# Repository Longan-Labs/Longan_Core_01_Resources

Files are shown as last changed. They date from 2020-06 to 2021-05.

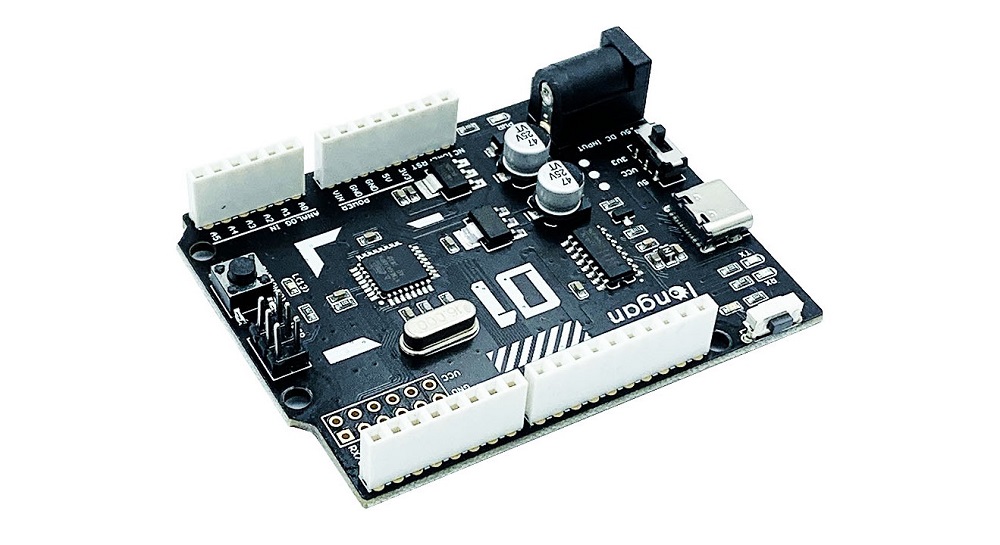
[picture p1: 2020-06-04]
images/1040008-2.jpg

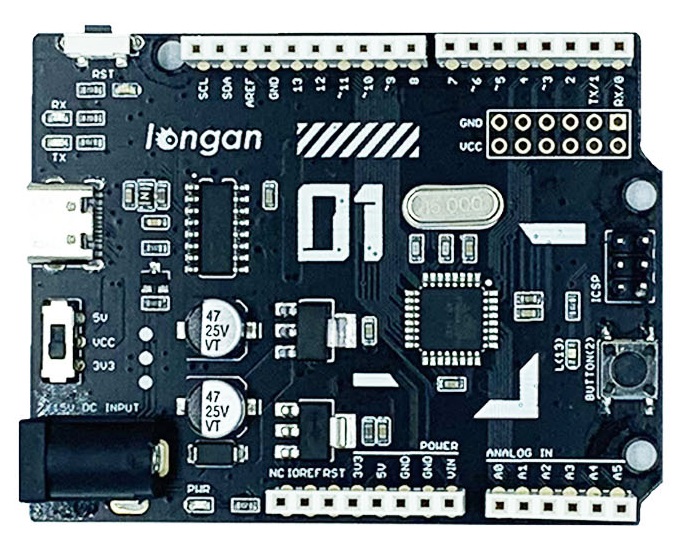
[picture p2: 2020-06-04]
images/1040008-1.jpg

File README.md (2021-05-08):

(https://www.longan-labs.cc/platform/arduino.html)

Resources of [Longan Core 01](https://www.longan-labs.cc/1040009.html)

Include:

1. Eagle File
2. Images
3. Drivers for CH340

Click on [Longan-Labs.cc](https://www.longan-labs.cc/) to get the product you need.

Contact [support@longan-labs.cc](support@longan-labs.cc) if you need help.

Analytics (https://github.com/igrigorik/ga-beacon)

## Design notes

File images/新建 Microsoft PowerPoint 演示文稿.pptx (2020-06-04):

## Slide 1

9


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
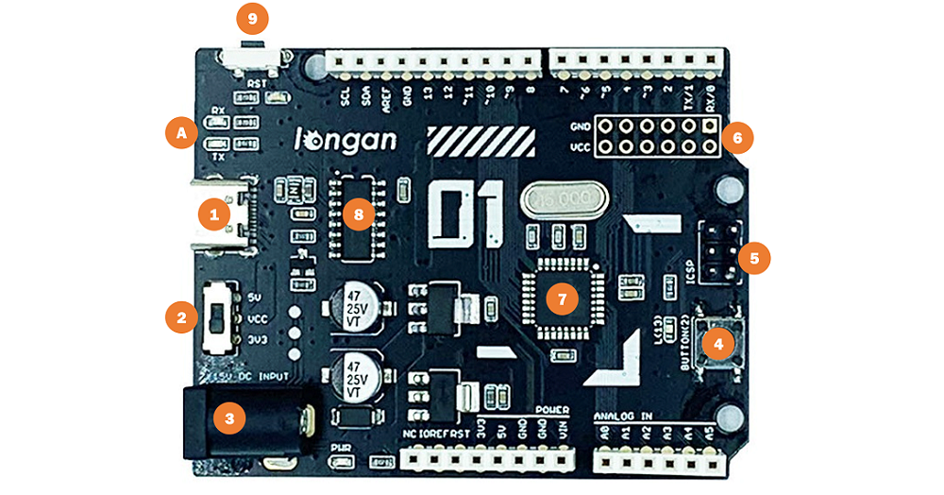
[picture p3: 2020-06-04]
images/hw.png

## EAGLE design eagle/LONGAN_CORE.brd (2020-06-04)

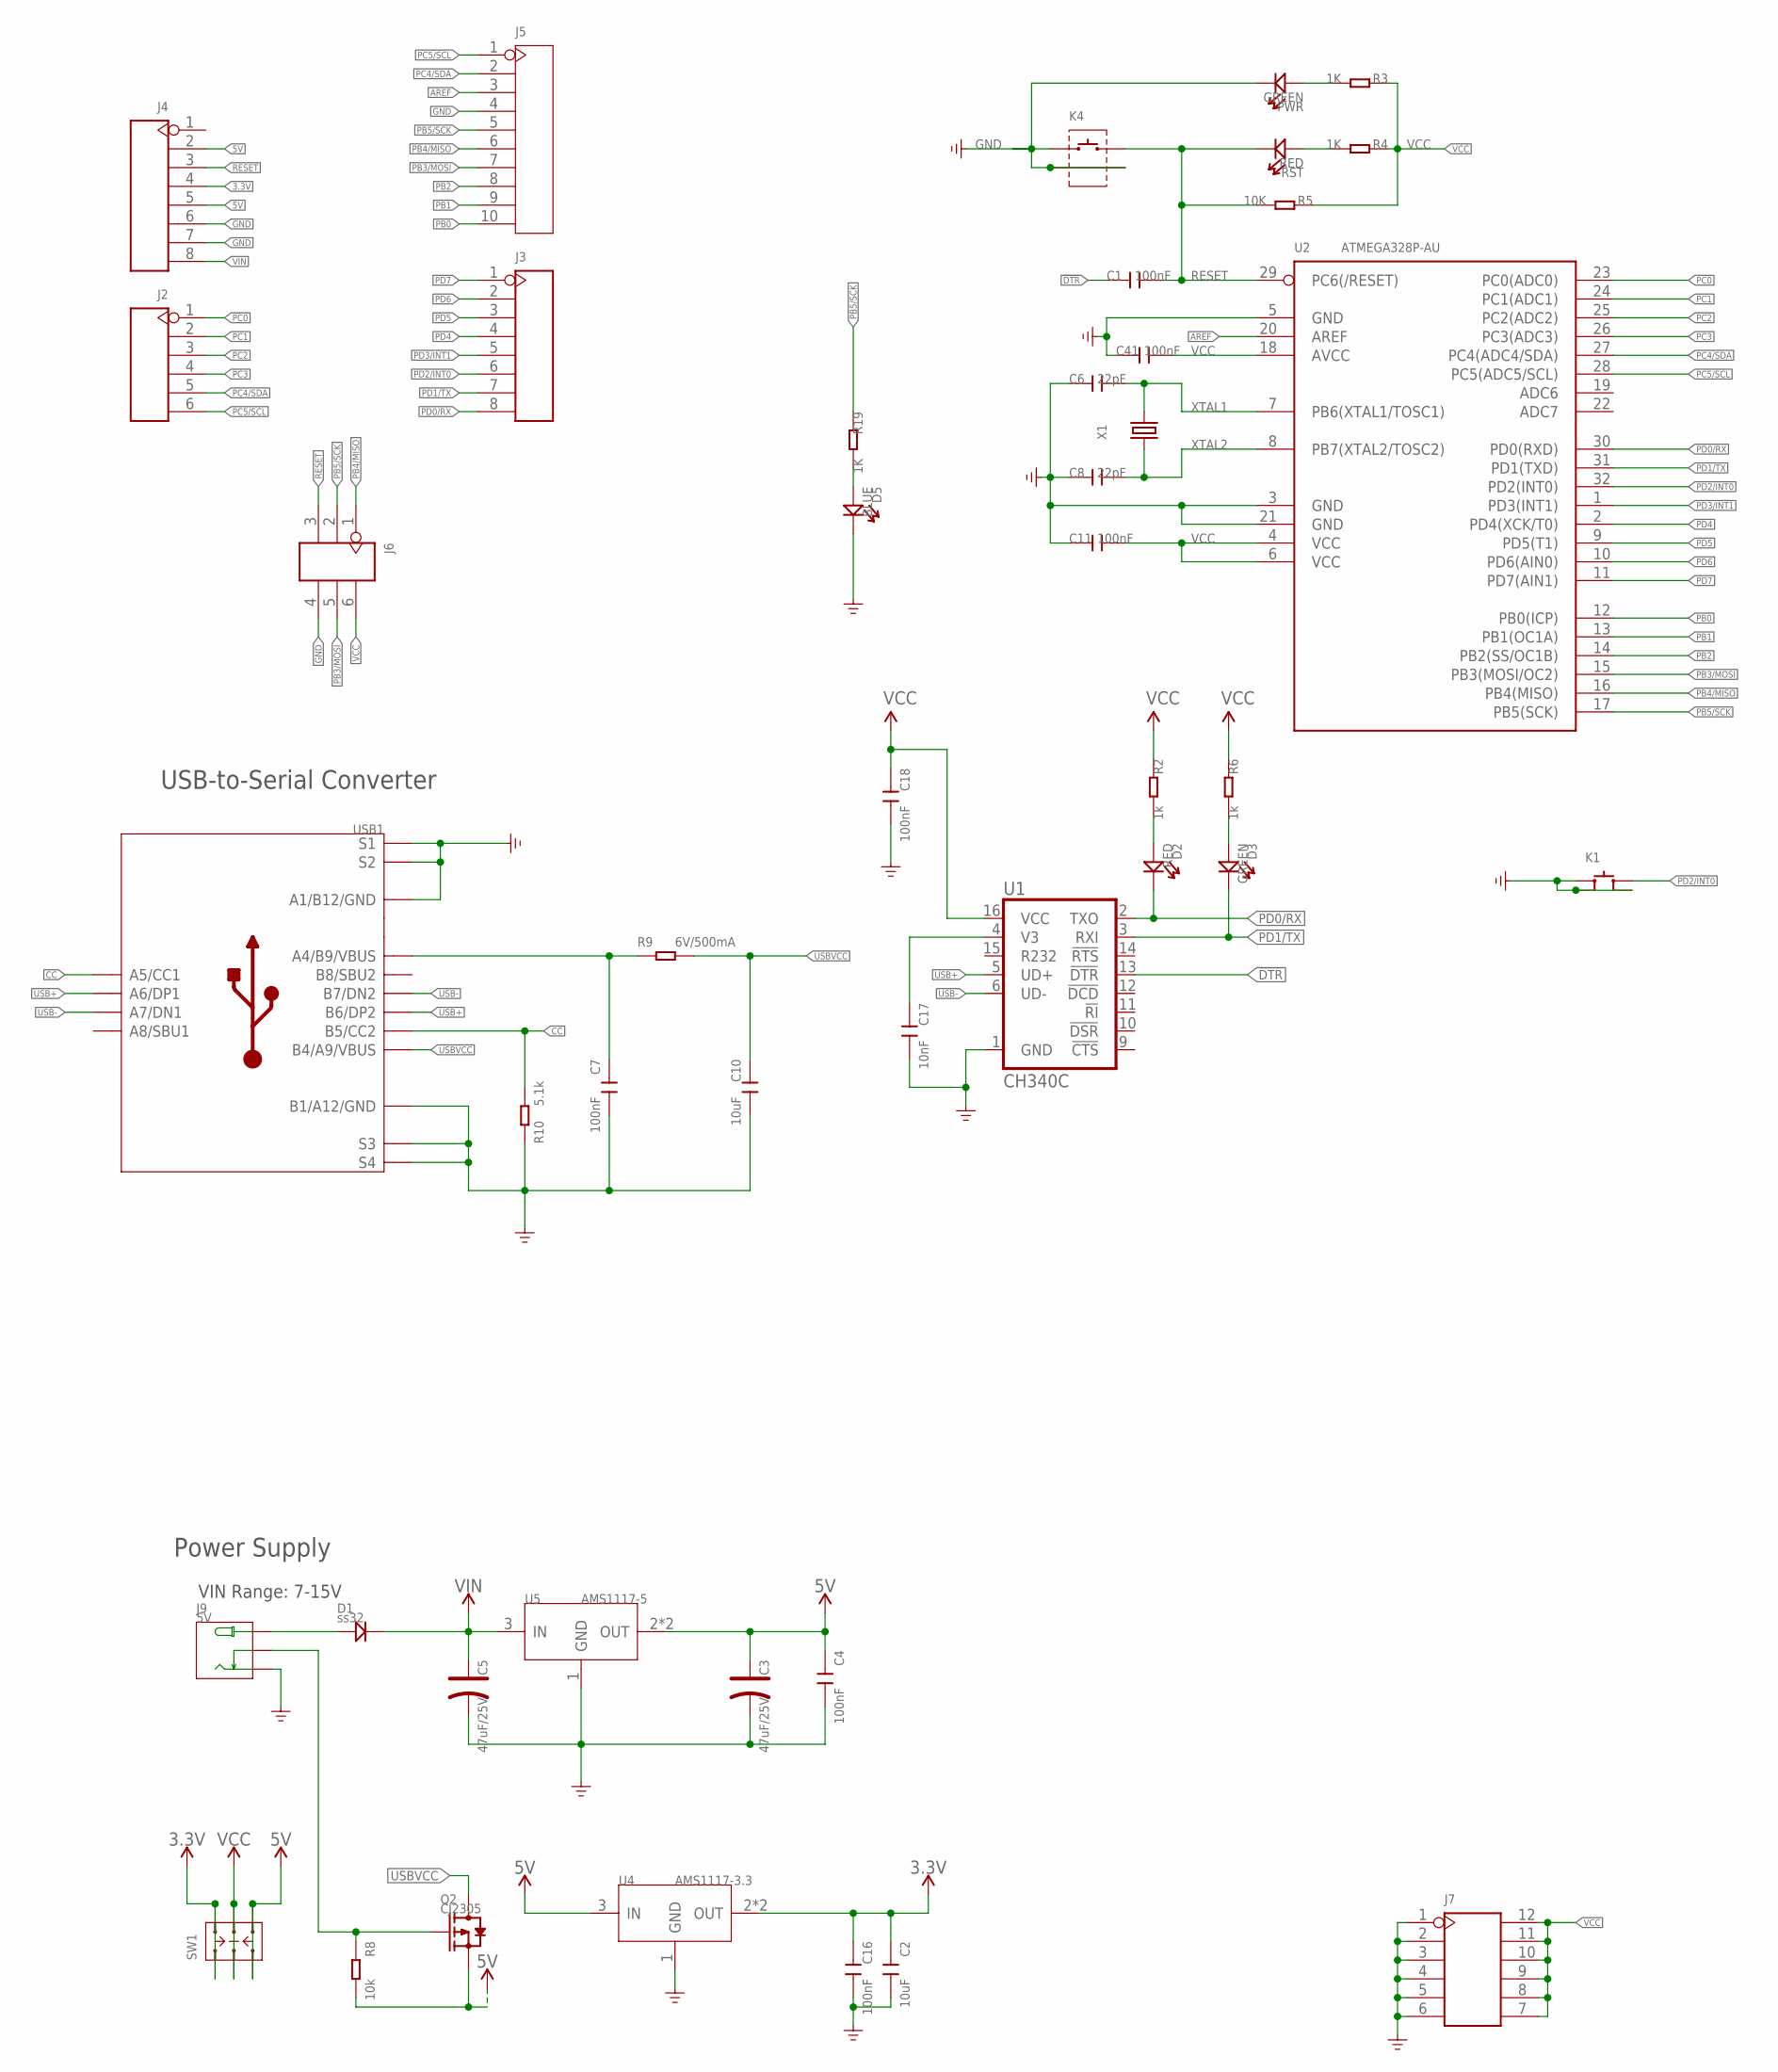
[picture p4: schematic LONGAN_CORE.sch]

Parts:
C1, C4, C7, C11, C16, C18, C41: 100nF; C0603
C2, C10: 10uF; C0603
C3, C5: 47uF/25V; ELECTRO-SMD-C-6MM
C6, C8: 22pF; C0603
C17: 10nF; C0603
D1: ss32; DO-214AC
D2: RED; LED-0603
D3: GREEN; LED-0603
D5: BLUE; LED-0603
J2: HEADER-6P-55/35MIL; H6-2.54
J3, J4: HEADER-8P-65/35MIL; H8-2.54-C65D35MIL
J5: HEADER-10P-2.54; H10-2.54
J6: HEADER-2X3P-2.54; H2X3-2.54
J7: HEADER-2X6P-2.54; H2X6-2.54
J9: 5V; DCJ3P-14.2X11.0X9.0MM
K1: BUTTON-4P-6.2X6.2; SW4-SMD-6.2X6.2MM
K4: BUTTON-2+2P; SW2+2P-7.7X2.75X3.95MM
PWR: GREEN; LED-0603
Q2: CJ2305; SOT-23
R2, R6: 1k; R0603
R3, R4, R19: 1K; R0603
R5: 10K; R0603
R8: 10k; R0603
R9: 6V/500mA; R0805
R10: 5.1k; R0603
RST: RED; LED-0603
SW1: SWITCH-2CH-6P-311010004; SW6-2.54-9.0X3.5X3.2+2.0MM
U1: CH340C; SO016
U2: ATMEGA328P-AU; TQFP32-0.8-7X7MM
U4: AMS1117-3.3; SOT-223
U5: AMS1117-5; SOT-223
USB1: TYPE-C-31-M-12; USB2.0-TYPE-C
X1: 16MHz; HC49US

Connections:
3.3V: C2.1, C16.1, J4.4, SW1.CH1A, SW1.CH2A, U4.2 (OUT), U4.TER (OUT)
5V: C3.+, C4.1, J4.2, J4.5, Q2.2 (S), R8.2, SW1.CH1B, SW1.CH2B, U4.3 (IN), U5.2 (OUT), U5.TER (OUT)
!DTR: C1.1, U1.13 (!DTR)
AREF: J5.3, U2.20 (AREF)
CC: R10.2, USB1.A5 (A5/CC1), USB1.B5 (B5/CC2)
GND: C2.2, C3.-, C4.2, C5.-, C6.1, C7.2, C8.1, C10.2, C11.1, C16.2, C17.2, C18.2, C41.1, D5.-, J4.6, J4.7, J5.4, J6.4, J7.1, J7.2, J7.3, J7.4, J7.5, J7.6, J9.-1 (-), K1.1 (A0), K1.3 (B1), K1.4 (A1), K4.1, K4.S1, K4.S2, PWR.-, R10.1, U1.1 (GND), U2.3 (GND), U2.5 (GND), U2.21 (GND), U4.1 (GND), U5.1 (GND), USB1.A1_B12 (A1/B12/GND), USB1.B1_A12 (B1/A12/GND), USB1.S1, USB1.S2, USB1.S3, USB1.S4, USB1.S5 (S1), USB1.S6 (S2)
INSERT: J9.-2 (CDN), Q2.1 (G), R8.1
unnamed: D5.+, R19.2
unnamed: C7.1, R9.1, USB1.A4_B9 (A4/B9/VBUS)
unnamed: D3.+, R6.2
unnamed: C17.1, U1.4 (V3)
unnamed: PWR.+, R3.2
unnamed: D2.+, R2.2
unnamed: R4.2, RST.+
PB0: J5.10, U2.12 (PB0(ICP))
PB1: J5.9, U2.13 (PB1(OC1A))
PB2: J5.8, U2.14 (PB2(SS/OC1B))
PB3/MOSI: J5.7, J6.5, U2.15 (PB3(MOSI/OC2))
PB4/MISO: J5.6, J6.1, U2.16 (PB4(MISO))
PB5/SCK: J5.5, J6.2, R19.1, U2.17 (PB5(SCK))
PC0: J2.1, U2.23 (PC0(ADC0))
PC1: J2.2, U2.24 (PC1(ADC1))
PC2: J2.3, U2.25 (PC2(ADC2))
PC3: J2.4, U2.26 (PC3(ADC3))
PC4/SDA: J2.5, J5.2, U2.27 (PC4(ADC4/SDA))
PC5/SCL: J2.6, J5.1, U2.28 (PC5(ADC5/SCL))
PD0/RX: D2.-, J3.8, U1.2 (TXO), U2.30 (PD0(RXD))
PD1/TX: D3.-, J3.7, U1.3 (RXI), U2.31 (PD1(TXD))
PD2/INT0: J3.6, K1.2 (B0), U2.32 (PD2(INT0))
PD3/INT1: J3.5, U2.1 (PD3(INT1))
PD4: J3.4, U2.2 (PD4(XCK/T0))
PD5: J3.3, U2.9 (PD5(T1))
PD6: J3.2, U2.10 (PD6(AIN0))
PD7: J3.1, U2.11 (PD7(AIN1))
PWRIN: D1.1 (+), J9.+
RESET: C1.2, J4.3, J6.3, K4.2, R5.2, RST.-, U2.29 (PC6(/RESET))
USB+: U1.5 (UD+), USB1.A6 (A6/DP1), USB1.B6 (B6/DP2)
USB-: U1.6 (UD-), USB1.A7 (A7/DN1), USB1.B7 (B7/DN2)
USBVCC: C10.1, Q2.3 (D), R9.2, USB1.B4_A9 (B4/A9/VBUS)
VCC: C11.2, C18.1, C41.2, J6.6, J7.7, J7.8, J7.9, J7.10, J7.11, J7.12, R2.1, R3.1, R4.1, R5.1, R6.1, SW1.COM1, SW1.COM2, U1.16 (VCC), U2.4 (VCC), U2.6 (VCC), U2.18 (AVCC)
VIN: C5.+, D1.2 (-), J4.8, U5.3 (IN)
XTAL1: C6.2, U2.7 (PB6(XTAL1/TOSC1)), X1.2
XTAL2: C8.2, U2.8 (PB7(XTAL2/TOSC2)), X1.1

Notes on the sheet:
USB-to-Serial Converter
Power Supply
VIN Range: 7-15V

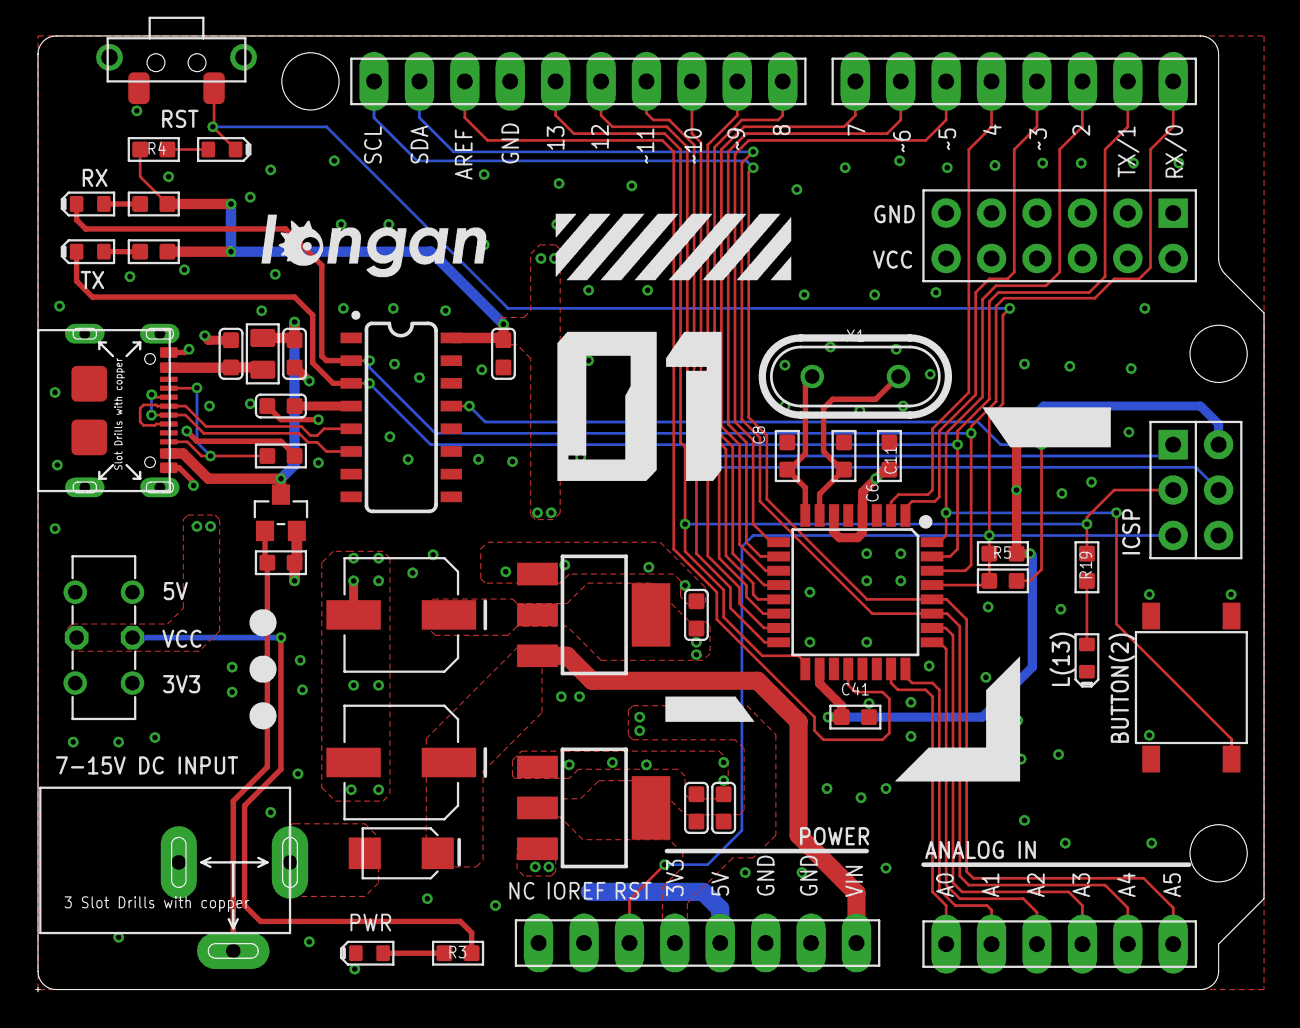
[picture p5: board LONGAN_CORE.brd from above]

Board: 2 copper layers, 68.6 x 53.4 mm, 46 parts (0 on the bottom side), 43 nets.

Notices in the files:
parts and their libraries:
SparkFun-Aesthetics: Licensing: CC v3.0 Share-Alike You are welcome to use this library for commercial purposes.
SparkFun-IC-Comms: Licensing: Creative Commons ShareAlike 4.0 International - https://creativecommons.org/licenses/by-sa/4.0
